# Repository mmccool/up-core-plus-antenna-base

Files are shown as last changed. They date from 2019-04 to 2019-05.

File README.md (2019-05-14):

# UP Core Plus Antenna Base
A 3D printable base for the [Aaeon UP Core Plus](https://up-shop.org/up-ai-edge/231-up-core-plus.html) to mount WiFi antennas.
Can work with either stick-on flat internal antennas or external RP-SMA antennas. 
Also provides space to mount the RTC battery internally and protects the bottom of the board.

## Mounting
To mount, use four to six M2.5 x 8 bolts, assuming the 9mm spacers that come with the board are used.
The spacers fit snugly inside the case, so you can omit the bolts if you want; the case can be held on by friction.
M2.6 bolts will not work; they will sort of go partway in, then jam (guess how I figured this out...)

## Antennas
You need internal antennas and\or RP-SMA pigtails with the smaller MHF4 connectors, not (the more common) U.FL connectors.

## Printing
My STLs may have a built-in scale of 94.5% in x and y to correct for my own printer's (mis-)calibration.  This can be easily adjusted in the OpenSCAD file.  If necessary, rescale for your printer when slicing or re-export the STL from OpenSCAD with a calibration factor suitable for your printer.  It's better to use the scale factors in the OpenSCAD file for this as the script is written to automatically keep the walls a nice multiple of the nozzle width.  The examples below were printed with a 0.8mm nozzle and a 0.2mm layer height in PLA.

## Renderings

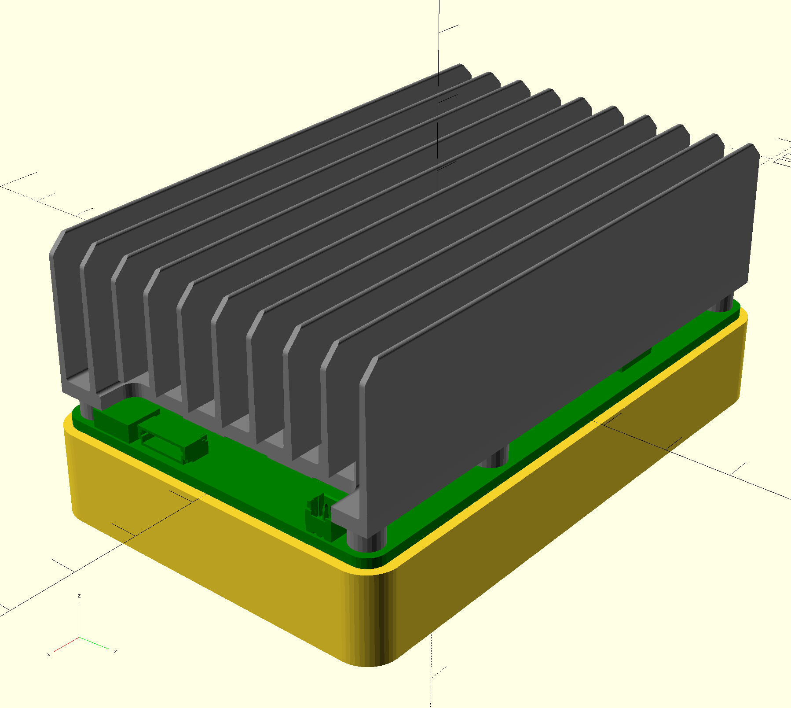
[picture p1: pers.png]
Perspective Rendering of Base with PCB and Heatsink, Front


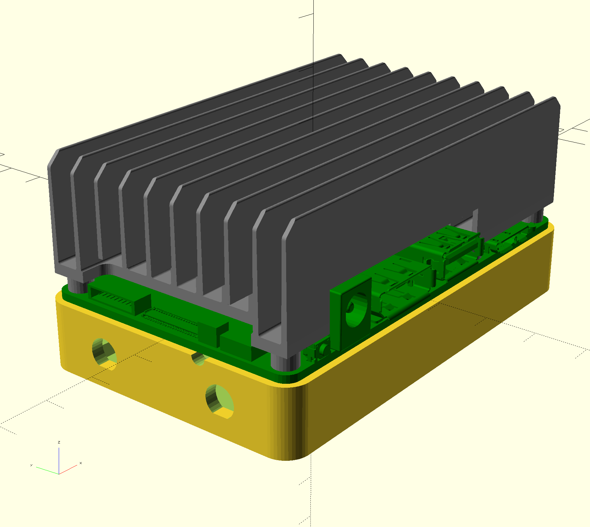
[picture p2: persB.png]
Perspective Rendering of Base with PCB and Heatsink, Back


## Images

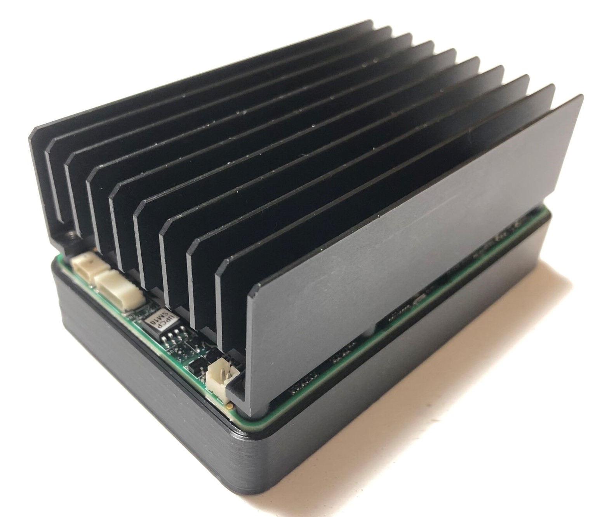
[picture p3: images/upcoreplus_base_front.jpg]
Image of Printed Base with UP Core Plus, Front


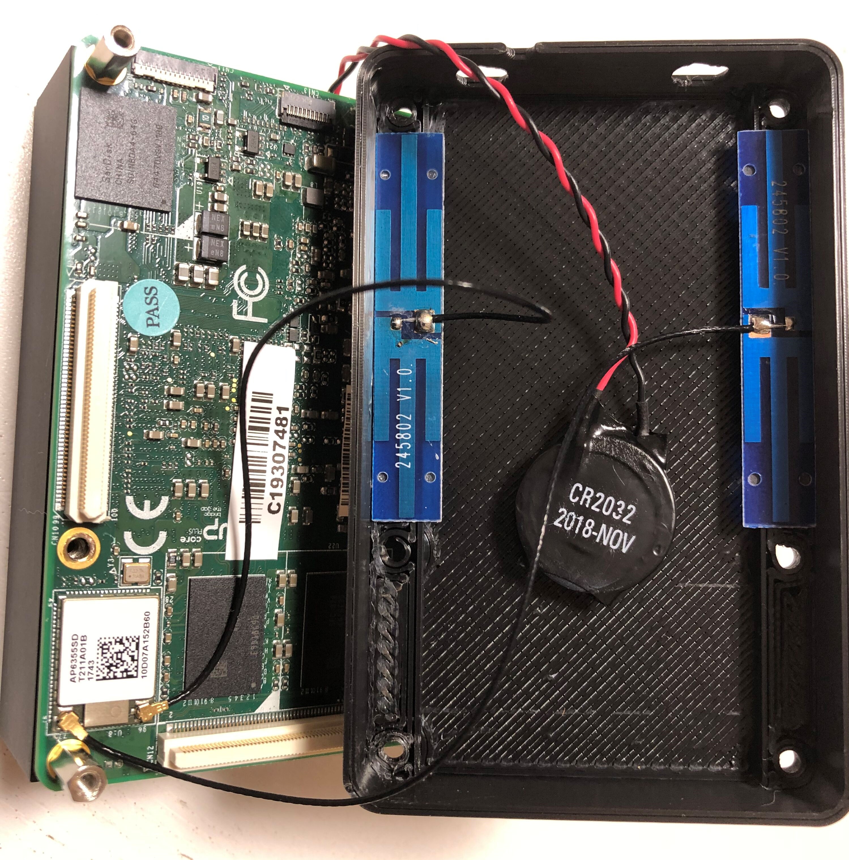
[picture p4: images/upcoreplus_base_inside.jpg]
Image of Printed Base with UP Core Plus, Inside


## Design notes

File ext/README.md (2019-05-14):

These were derived from the 3D files provided by Aaeon, and are used for visualization, not printing.
These are not subject to the license in the directory above, but to Aaeon's:
See: https://downloads.up-community.org/download/up-core-plus-3d-drawing/

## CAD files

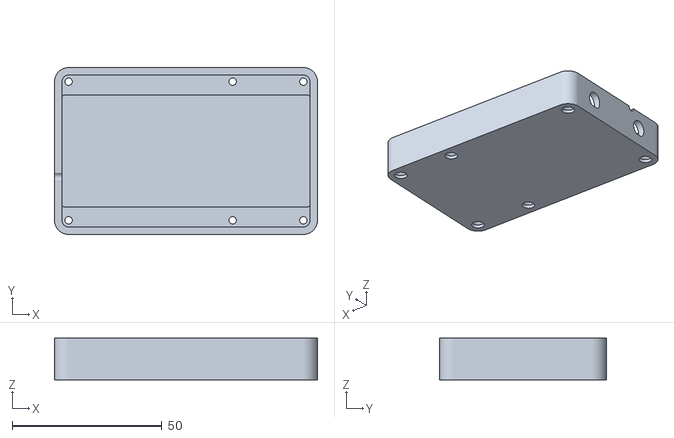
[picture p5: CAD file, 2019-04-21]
antbase.stl
87.9 x 55.7 x 14.0

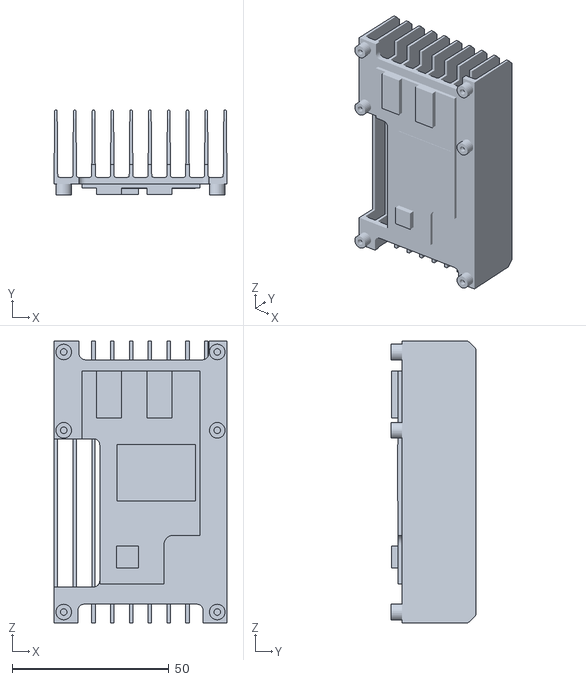
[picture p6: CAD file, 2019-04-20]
ext/heatsink.stl
55.2 x 27.2 x 90.0

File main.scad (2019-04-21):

// UP Core Plus Antenna Base
// Developed by: Michael McCool
// Copyright 2018 Michael McCpp;
// License: CC BY 3.0. See LICENSE.md
include <tols.scad>
//include <smooth_model.scad>
include <smooth_make.scad>
include <bolt_params.scad>
use <bolts.scad>

// scale factors (to correct for imperfect printer)
sz = 1.0;
sxy = 0.945;

// critical dimensions that must be a multiple of nozzle width or layer height
nozzle_r = 0.8;
layer_h = 0.2;
wall_t = (3*nozzle_r + tol)/sxy;
floor_h = (10*layer_h + tol)/sz;

// whether to include RP-SMA holes
use_sma = true;

module ext() {
  color("grey") {
    translate([2.5,0,3.8])
      rotate([90,0,0])
        rotate([0,90,0])
          import("ext/heatsink.stl", convexity=10);
  }
  color("green") {
    import("ext/pcb.stl", convexity=10);
  }
}

standoff_or = 4.64/2;
standoff_os = 6;
standoff_ir = 2.5/2;
standoff_is = 20;
standoff_h = 9;

module standoff() {
  color("silver") difference() {
    cylinder(r=standoff_or,h=standoff_h,$fn=standoff_os);
    translate([0,0,-1]) cylinder(r=standoff_ir,h=standoff_h+2,$fn=standoff_is);
  }
}

pcb_xs = 83;
pcb_xi = 2.5;
pcb_xo = 19;
pcb_ys = 49;
pcb_yi = 0;
module standoffs() {
  translate([-pcb_xs/2+pcb_xi,-pcb_ys/2+pcb_yi,-standoff_h]) standoff();
  translate([-pcb_xs/2+pcb_xi, pcb_ys/2+pcb_yi,-standoff_h]) standoff();
  translate([ pcb_xo,-pcb_ys/2+pcb_yi,-standoff_h]) standoff();
  translate([ pcb_xo, pcb_ys/2+pcb_yi,-standoff_h]) standoff();
  translate([ pcb_xs/2+pcb_xi,-pcb_ys/2+pcb_yi,-standoff_h]) standoff();
  translate([ pcb_xs/2+pcb_xi, pcb_ys/2+pcb_yi,-standoff_h]) standoff();
}

base_cr = 10/2;
// base_ir = standoff_or + 1;
base_ir = base_cr - wall_t;
base_iir = 1;
base_sm = 50;
base_h = 5;
base_hh = floor_h;
base_H = base_h + standoff_h;
base_br = 2.6/2;
base_csh = 2.5; // bolt head height
base_csr = 5/2;
base_csdr = base_csr - base_br;
base_pw = 2*standoff_or;

module bolt_hole() {
  translate([0,0,-1]) 
    cylinder(r=base_br,h=base_h+2,$fn=base_sm);
  translate([0,0,-1]) 
    cylinder(r=base_csr,h=base_csh+1-base_csdr,$fn=base_sm);
  translate([0,0,base_csh-base_csdr-10*eps]) 
    cylinder(r1=base_csr,r2=base_br,h=base_csdr,$fn=base_sm);
}

sma_r = 6.27/2 + tol;
sma_f = 6.3-5.83;
sma_yo = 14;
module sma_hole() {
  rotate([0,-90,0]) {
    difference() {
      cylinder(r=sma_r,h=10,$fn=30);
      translate([sma_f-3*sma_r,-sma_r,-1]) 
        cube([2*sma_r,2*sma_r,12]);
    }
  }
}

module base() {
  difference() {
    // exterior
    hull() {
      translate([0,0,-base_H]) {
        translate([-pcb_xs/2+pcb_xi,-pcb_ys/2+pcb_yi,0]) 
          cylinder(r=base_cr,h=base_H,$fn=base_sm);
        translate([-pcb_xs/2+pcb_xi, pcb_ys/2+pcb_yi,0]) 
          cylinder(r=base_cr,h=base_H,$fn=base_sm);
        translate([ pcb_xs/2+pcb_xi,-pcb_ys/2+pcb_yi,0]) 
          cylinder(r=base_cr,h=base_H,$fn=base_sm);
        translate([ pcb_xs/2+pcb_xi, pcb_ys/2+pcb_yi,0]) 
          cylinder(r=base_cr,h=base_H,$fn=base_sm);
      }
    }
    // cavity
    hull() {
      translate([0,0,-standoff_h]) {
        translate([-pcb_xs/2+pcb_xi,-pcb_ys/2+pcb_yi,0]) 
          cylinder(r=base_ir,h=standoff_h+1,$fn=base_sm);
        translate([-pcb_xs/2+pcb_xi, pcb_ys/2+pcb_yi,0]) 
          cylinder(r=base_ir,h=standoff_h+1,$fn=base_sm);
        translate([ pcb_xs/2+pcb_xi,-pcb_ys/2+pcb_yi,0]) 
          cylinder(r=base_ir,h=standoff_h+1,$fn=base_sm);
        translate([ pcb_xs/2+pcb_xi, pcb_ys/2+pcb_yi,0]) 
          cylinder(r=base_ir,h=standoff_h+1,$fn=base_sm);
      }
    }
    // central cavity
    hull() {
      translate([0,0,-standoff_h-base_h+base_hh]) {
        translate([-pcb_xs/2+pcb_xi-base_ir+base_iir+eps,
                   -pcb_ys/2+pcb_yi+base_pw+base_iir,0]) 
          cylinder(r=base_iir,h=standoff_h+1,$fn=base_sm);
        translate([-pcb_xs/2+pcb_xi-base_ir+base_iir+eps, 
                    pcb_ys/2+pcb_yi-base_pw-base_iir,0]) 
          cylinder(r=base_iir,h=standoff_h+1,$fn=base_sm);
        translate([ pcb_xs/2+pcb_xi+base_ir-base_iir-eps,
                   -pcb_ys/2+pcb_yi+base_pw+base_iir,0]) 
          cylinder(r=base_iir,h=standoff_h+1,$fn=base_sm);
        translate([ pcb_xs/2+pcb_xi+base_ir-base_iir-eps, 
                    pcb_ys/2+pcb_yi-base_pw-base_iir,0]) 
          cylinder(r=base_iir,h=standoff_h+1,$fn=base_sm);
      }
    }
    // bolt holes
    translate([0,0,-standoff_h-base_h-eps]) {
      translate([-pcb_xs/2+pcb_xi,-pcb_ys/2+pcb_yi,0]) 
        bolt_hole();
      translate([-pcb_xs/2+pcb_xi, pcb_ys/2+pcb_yi,0]) 
        bolt_hole();
      translate([ pcb_xo,-pcb_ys/2+pcb_yi,0]) 
        bolt_hole();
      translate([ pcb_xo, pcb_ys/2+pcb_yi,0]) 
        bolt_hole();
      translate([ pcb_xs/2+pcb_xi,-pcb_ys/2+pcb_yi,0]) 
        bolt_hole();
      translate([ pcb_xs/2+pcb_xi, pcb_ys/2+pcb_yi,0]) 
        bolt_hole();
    }
    // RTC battery wire notch
    translate([-pcb_xs/2+3,-9.25,0])
      rotate([0,-90,0])
        cylinder(r=3/2,h=10,$fn=20);
    // SMA holes
    if (use_sma) {
      translate([-pcb_xs/2+3,-sma_yo,-base_H/2])
        sma_hole();
      translate([-pcb_xs/2+3, sma_yo,-base_H/2])
        sma_hole();
    }
  }
}

module assembly() {
  ext();
  standoffs();
  //translate([0,0,-0.5]) 
  //  color([0.5,0.5,0.5,1]) 
  base();
}

assembly();

// to print
//scale([sxy,sxy,sz]) base();

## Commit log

2019-04-20 pcb, heatsink, and standoffs
    [heatsink.stl, main.scad]
2019-04-20 base with holes and notches
    [main.scad, main.stl]
2019-04-21 scale and manage critical dimensions
    [main.scad, main.stl]
